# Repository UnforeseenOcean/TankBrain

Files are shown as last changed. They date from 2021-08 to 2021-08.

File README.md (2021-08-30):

# TankBrain
Official repository for TankBrain, a replacement board for Academy and other motorized vehicle models

# What is this?
This is an Arduino-compatible* board with remote controller that replaces either the old 30/40MHz band remote control or wired remote on models from Academy Plastic Models or other companies.
Currently it supports Academy's wired motorized tank models (the benchmark being their ROK K1A1 tank model), but with some support it should be easy to make it support nearly all models.

\*: Arduino-compatible in this context means "Arduino IDE compatible". The board in no way, shape or form can support peripherals made for Arduino Uno and other boards.

# Goals
- To create a universal board that fits into most models, including some toy vehicles (such as tanks or cars)
- To make a firmware that handles most functions called by signals through 433MHz ASK/OOK module

# Information
This board currently uses GoodRF SRX887 and STX887 pair, which has a good range of operation with least amount of latency (due to it not containing any signal-to-binary conversion) from the online reviews.

The operating state table is as follows:
```
ABCD (AIN1,AIN2,BIN1,BIN2)
0000 (Stop)
0001 (Backwards Left Strafe)
0010 (Right Strafe)
0011 (Invalid/Unused)
0100 (Backwards Right Strafe)
0101 (Backward)
0110 (Right Turn In Place)
0111 (Invalid/Unused)
1000 (Left Strafe)
1001 (Left Turn In Place)
1010 (Forward)
1011 (Invalid/Unused)
1100 (Invalid/Unused)
1101 (Invalid/Unused)
1110 (Invalid/Unused)
1111 (Brake)
```
Simulation for engine starting and firing is handled by switching the movement state through this table:
```
1010 (Start of "Engine start" movement set)
0101
1010
0101
1010
0101 (Start of "Fire" movement set)
1010
0101
1111
0000 (End)
```
There is a plan to add support for external sound modules (DFPlayer Mini / Serial MP3 player modules)

The board needs some revision and quality/function check, as it has not been made yet. However this is what the board could look like if the current design is made:



Believe it or not this is the second big revision -- the first one was... not good.

# Credits
Pololu - DRV8833 circuit design

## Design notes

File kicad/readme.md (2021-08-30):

# KiCad project files
Yes, they're here. Please make improvements to this, since I have no idea if this is going to do the job or not!

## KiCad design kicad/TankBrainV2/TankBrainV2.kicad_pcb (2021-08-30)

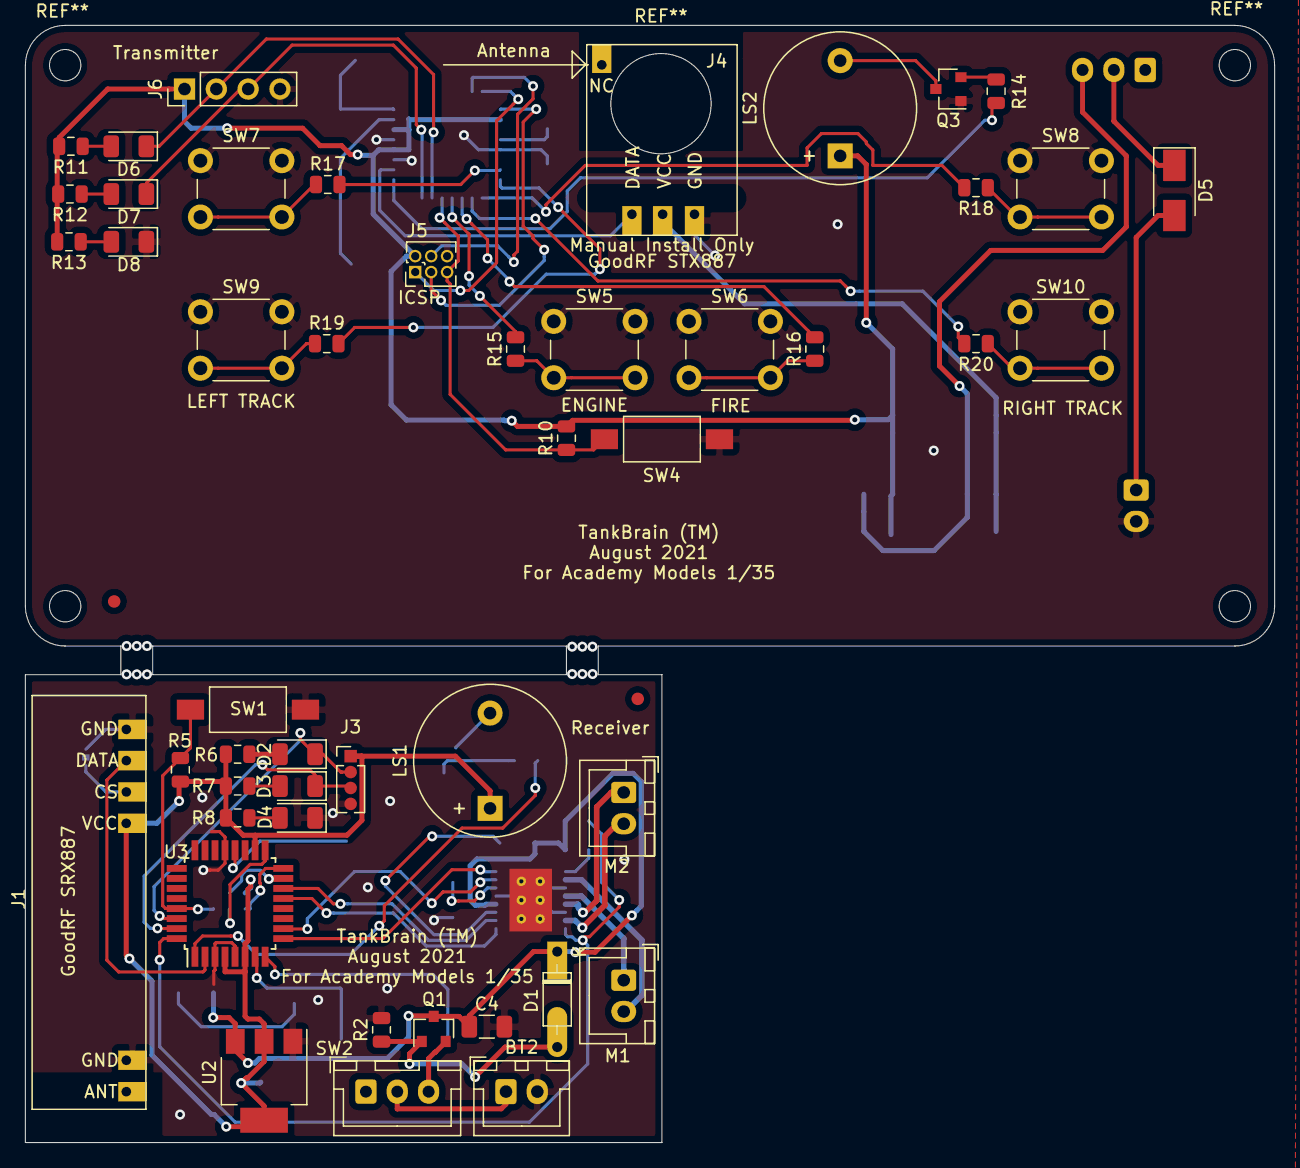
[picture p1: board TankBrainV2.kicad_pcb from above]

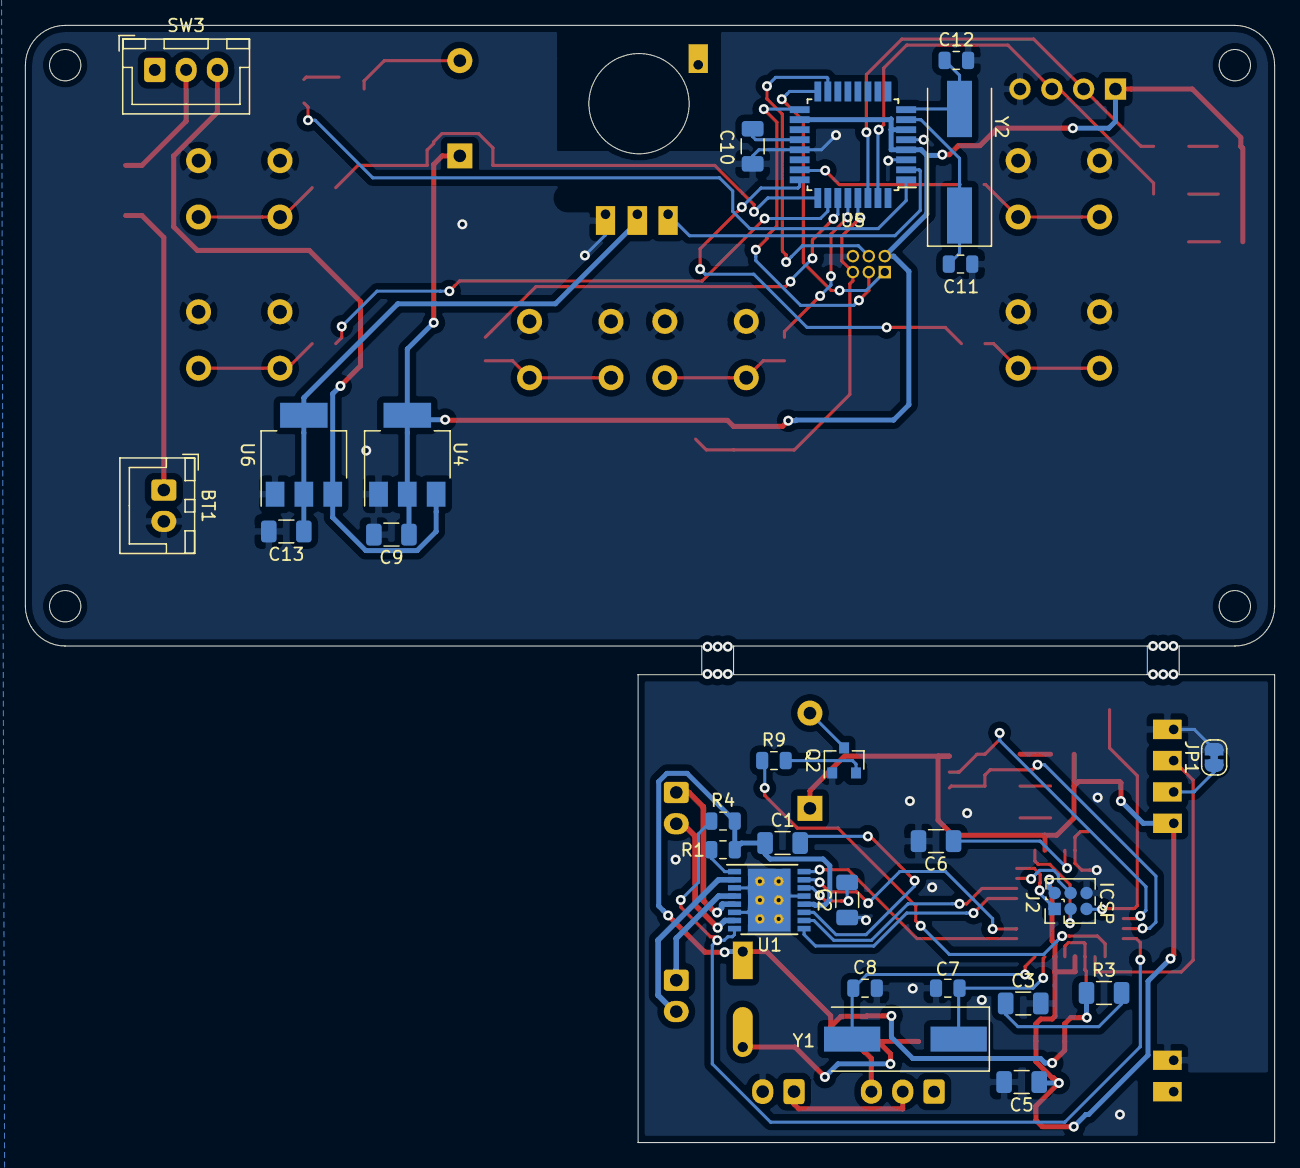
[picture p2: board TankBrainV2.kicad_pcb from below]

Board: 2 copper layers, 99.7 x 89.2 mm, 75 parts (27 on the bottom side), 69 nets.

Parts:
BT1: 9V; JST_XH_B2B-XH-A_1x02_P2.50mm_Vertical
BT2: 4.3V; JST_XH_B2B-XH-A_1x02_P2.50mm_Vertical
C1, C4, C5, C6, C9, C10, C13: 100nF; C_1206_3216Metric
C2: 2.2uF; C_1206_3216Metric
C3: 10uF; C_1206_3216Metric
C7, C8, C11, C12: 22nF; C_0805_2012Metric
D1: 6.8V; D_DO-35_SOD27_P7.62mm_Horizontal
D2, D6: RX; LED_1206_3216Metric
D3, D7: TX; LED_1206_3216Metric
D4, D8: PWR; LED_1206_3216Metric
D5: 1N4001; D_SMA
J1: 433RX; SRX887
J2, J5: ISP; PinHeader_2x03_P1.27mm_Vertical
J3: UART; PinHeader_1x04_P1.27mm_Vertical
J4: 433TX; STX887
J6: UART; PinHeader_1x04_P2.54mm_Vertical
JP1: GRF; SolderJumper-2_P1.3mm_Bridged_RoundedPad1.0x1.5mm
LS1, LS2: Speaker; Buzzer_12x9.5RM7.6
M1: L; JST_XH_B2B-XH-A_1x02_P2.50mm_Vertical
M2: R; JST_XH_B2B-XH-A_1x02_P2.50mm_Vertical
Q1: AO3401; SOT-23
Q2, Q3: 2N3904; SOT-23
R1, R4: 47K; R_0805_2012Metric
R2: 100K; R_0805_2012Metric
R3: 1R; R_1206_3216Metric
R5, R10: 10K; R_0805_2012Metric
R6, R7, R8, R9, R11, R12, R13, R14, R15, R16, R17, R18, R19, R20: 1K; R_0805_2012Metric
SW1, SW4: RESET; SW_SPST_FSMSM
SW2: POWER_RX; JST_XH_B3B-XH-A_1x03_P2.50mm_Vertical
SW3: POWER_TX; JST_XH_B3B-XH-A_1x03_P2.50mm_Vertical
SW5: ENGINE; SW_PUSH_6mm
SW6: FIRE; SW_PUSH_6mm
SW7: UP_LEFT; SW_PUSH_6mm
SW8: UP_RIGHT; SW_PUSH_6mm
SW9: DOWN_LEFT; SW_PUSH_6mm
SW10: DOWN_RIGHT; SW_PUSH_6mm
U1: DRV8833PWP; HTSSOP-16-1EP_4.4x5mm_P0.65mm_EP3.4x5mm_Mask2.46x2.31mm_The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
U2, U6: AMS1117-3.3; SOT-223-3_TabPin2
U3, U5: ATmega328P-AU; TQFP-32_7x7mm_P0.8mm
U4: AMS1117-5.0; SOT-223-3_TabPin2
Y1: 8MHz; Crystal_SMD_HC49-SD
Y2: 16MHz; Crystal_SMD_HC49-SD

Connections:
A1: U1.16, U3.9
A2: U1.15, U3.10
B1: U1.9, U3.13
B2: U1.10, U3.14
BUZZER: R9.1, U3.1
BZR: R14.1, U5.1
CK: J5.3, U5.17
ENGINE: R15.2, U5.28
FAULT: R4.1, U1.8, U3.32
FIRE: R16.2, U5.27
GND: BT1.2, BT2.2, C2.1, C3.2, C4.2, C5.2, C6.2, C7.2, C8.2, C9.2, C10.2, C11.2, C12.2, C13.2, D4.1, D8.1, J1.2, J1.6, J2.6, J3.4, J4.4, J5.6, J6.4, JP1.2, Q2.1, Q3.1, R2.2, SW1.2, SW4.2, SW5.1, SW6.1, SW7.1, SW8.1, SW9.1, SW10.1, U1.3, U1.6, U1.13, U1.17, U2.1, U3.3, U3.5, U3.21, U4.1, U5.3, U5.5, U5.21, U6.1
LO1: M1.2, U1.2
LO2: M1.1, U1.4
LSWD: R19.2, U5.24
LSWU: R17.2, U5.23
MI: J5.1, U5.16
MISO: J2.1, U3.16
MO: J5.4, U5.15
MOSI: J2.4, U3.15
unnamed: BT1.1, D5.2
unnamed: C1.2, U1.11
unnamed: C2.2, U1.14
unnamed: C3.1, R3.2
unnamed: C6.1, U3.20
unnamed: C7.1, U3.7, Y1.1
unnamed: C8.1, U3.8, Y1.2
unnamed: C10.1, U5.20
unnamed: C11.1, U5.7, Y2.1
unnamed: C12.1, U5.8, Y2.2
unnamed: C13.1, J4.3, U6.2
unnamed: D1.2, Q1.1, R2.1
unnamed: D2.2, R6.1
unnamed: D3.2, R7.1
unnamed: D4.2, R8.1
unnamed: D5.1, SW3.2
unnamed: D6.2, R11.1
unnamed: D7.2, R12.1
unnamed: D8.2, R13.1
unnamed: J1.4, JP1.1
unnamed: LS1.2, Q2.3
unnamed: LS2.2, Q3.3
unnamed: Q1.2, SW2.3
unnamed: Q2.2, R9.2
unnamed: Q3.2, R14.2
unnamed: R1.1, U1.1
unnamed: R15.1, SW5.2
unnamed: R16.1, SW6.2
unnamed: R17.1, SW7.2
unnamed: R18.1, SW8.2
unnamed: R19.1, SW9.2
unnamed: R20.1, SW10.2
unnamed: SW3.3, U4.3, U6.3
RESET: J2.5, R5.1, SW1.1, U3.29
RF: J1.5, U3.2
RO1: M2.2, U1.7
RO2: M2.1, U1.5
RST: J5.5, R10.1, SW4.1, U5.29
RSWD: R20.2, U5.26
RSWU: R18.2, U5.25
RX: D2.1, J3.2, U3.30
RXQ: D6.1, J6.2, U5.30
SCK: J2.3, U3.17
TX: D3.1, J3.3, U3.31
TXD: J4.2, U5.2
TXQ: D7.1, J6.3, U5.31
VCC: C5.1, J1.3, J2.2, J3.1, LS1.1, R5.2, R6.2, R7.2, R8.2, U2.2, U3.4, U3.6, U3.18
VCCQ: C9.1, J5.2, J6.1, LS2.1, R10.2, R11.2, R12.2, R13.2, U4.2, U5.4, U5.6, U5.18
VD: C1.1, C4.1, D1.1, Q1.3, R1.2, R3.1, R4.2, U1.12, U2.3
VDD: BT2.1, SW2.2
